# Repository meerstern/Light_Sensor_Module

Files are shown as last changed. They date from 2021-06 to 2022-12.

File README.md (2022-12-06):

# Light_Sensor_Module

Light Sensor Module with APDS-9008-020

## 概要 
  * アナログ光センサ[APDS-9008-020][1]を用いた光センサ基板です  
  * 人の目に近いスペクトル応答性と広い照明範囲にわたる出力線形性のセンサを使用しています  
  * 光強度のアナログ出力(A)と可変抵抗で調整可能な閾値によるデジタル出力(D)を備えています  
  * デジタル出力の状態はLEDで確認できます  
  * コネクタはGrove互換コネクタとなっており、3.3V/5V電源に対応しています  
  * 電源は3V~5.5Vに対応しています  
  * 光センサ感度の可変抵抗、デジタル出力の閾値の可変抵抗を備えています  
  * 本センサは環境負荷の大きなCdSを使用していません  
  * 基板サイズ25mm x30mm、固定穴M3x4 幅19mm x24mm  

## 注意 
  * 可変抵抗は強く回したり、速く動かすと破損する場合があります。ゆっくり動かしてください     
  * 基板裏側の光センサは衝撃や外力に非常に弱いため、取り扱いに注意してください    
 
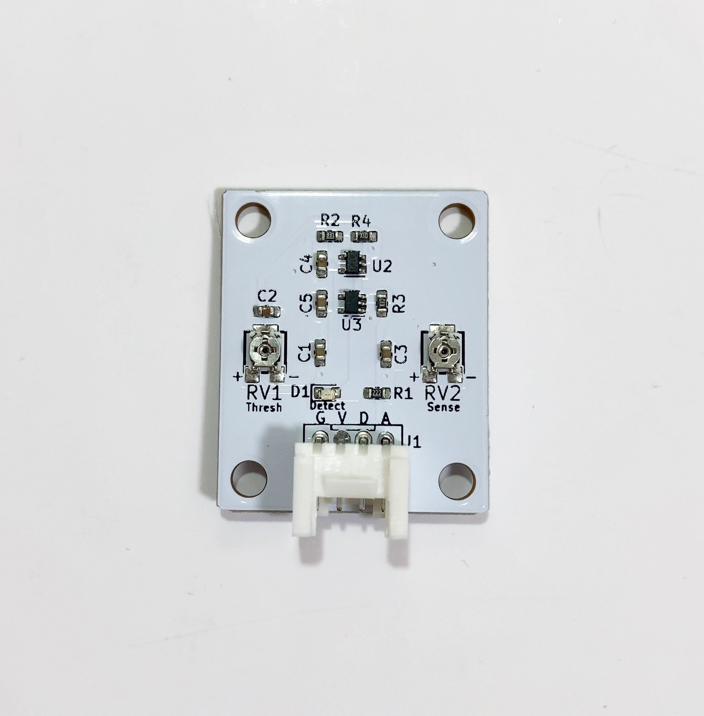
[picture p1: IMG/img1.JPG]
 
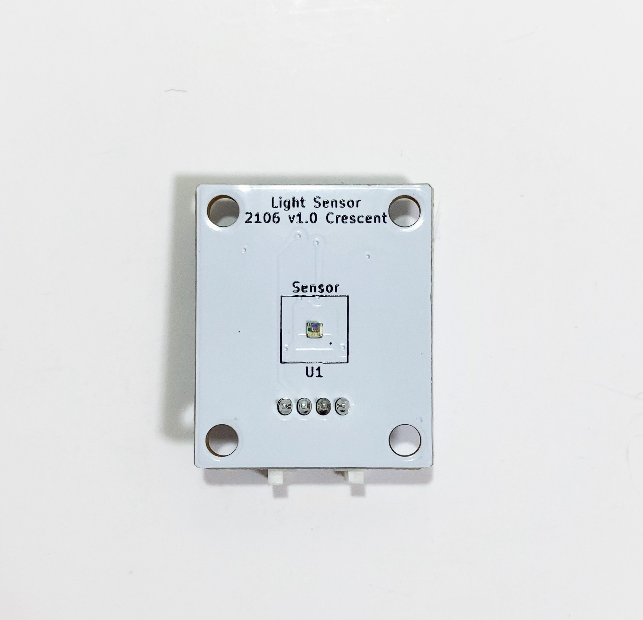
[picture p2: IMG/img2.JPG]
 
 
## 販売サイト
  * [スイッチサイエンス][2]
 
[1]: https://jp.broadcom.com/products/optical-sensors/ambient-light-photo-sensors/apds-9008 "*1"
[2]: https://www.switch-science.com/products/7394
MIT Lisense

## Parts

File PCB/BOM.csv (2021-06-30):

Elecrow PN | Parts | Value | Package | QTY | Digikey/Mouser/Manufacturer Part | Remark/ Link
 | U3 | LM321 | SOT-353_SC-70-5 | 1 | 595-TLV316IDCKR
 | U2 | LMV331 | SOT-353_SC-70-5 | 1 | 595-LMV331IDCKR
 | U1 | APDS-9008 | APDS-9008 | 1 | 630-APDS-9008-020
 | RV2,RV1 | 10k | rcl-RTRIMCVR42A | 2 | 652-TC33X-2-103E
C22859 | R4,R3 | 10 | R_0603_1608Metric | 2
C23138 | R2 | 330 | R_0603_1608Metric | 1
C4190 | R1 | 2.2k | R_0603_1608Metric | 1
 | J1 | Grove | GROVE | 1 | 713-110990037
4040806A | D1 | LED | LED_0603_1608Metric | 1
C14663 | C5,C4,C3,C2,C1 | 0.1u | C_0603_1608Metric | 5

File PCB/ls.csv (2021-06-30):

ID | 参照記号 | パッケージ | 数 | 名称 | Supplier and ref
1 | H4,H3,H2,H1 | MountingHole_3.2mm_M3 | 4 | MountingHole
2 | U3 | SOT-353_SC-70-5 | 1 | LM321
3 | U2 | SOT-353_SC-70-5 | 1 | LMV331
4 | U1 | APDS-9008 | 1 | APDS-9008
5 | RV2,RV1 | rcl-RTRIMCVR42A | 2 | 10k
6 | R4,R3 | R_0603_1608Metric | 2 | 10
7 | R2 | R_0603_1608Metric | 1 | 330
8 | R1 | R_0603_1608Metric | 1 | 2.1k
9 | J1 | GROVE | 1 | Grove
10 | D1 | LED_0603_1608Metric | 1 | LED
11 | C5,C4,C3,C2,C1 | C_0603_1608Metric | 5 | 0.1u

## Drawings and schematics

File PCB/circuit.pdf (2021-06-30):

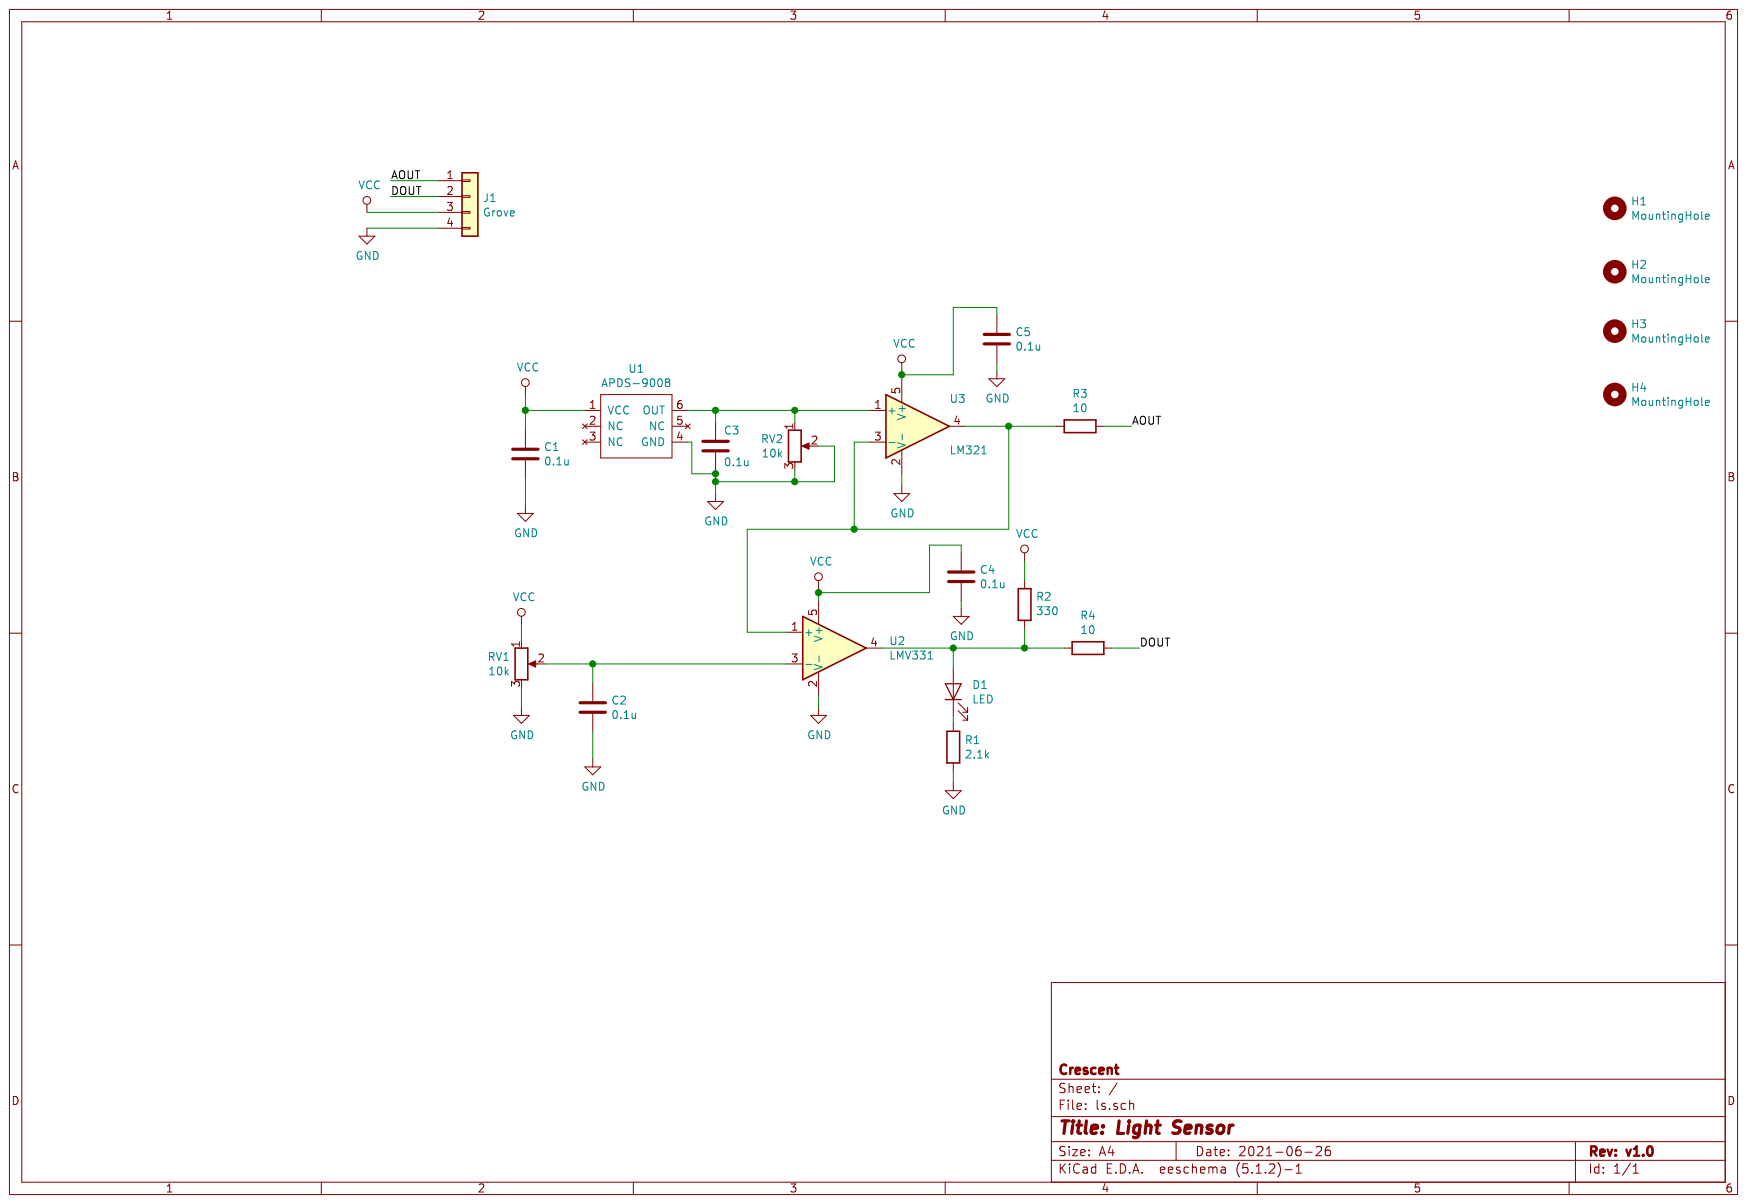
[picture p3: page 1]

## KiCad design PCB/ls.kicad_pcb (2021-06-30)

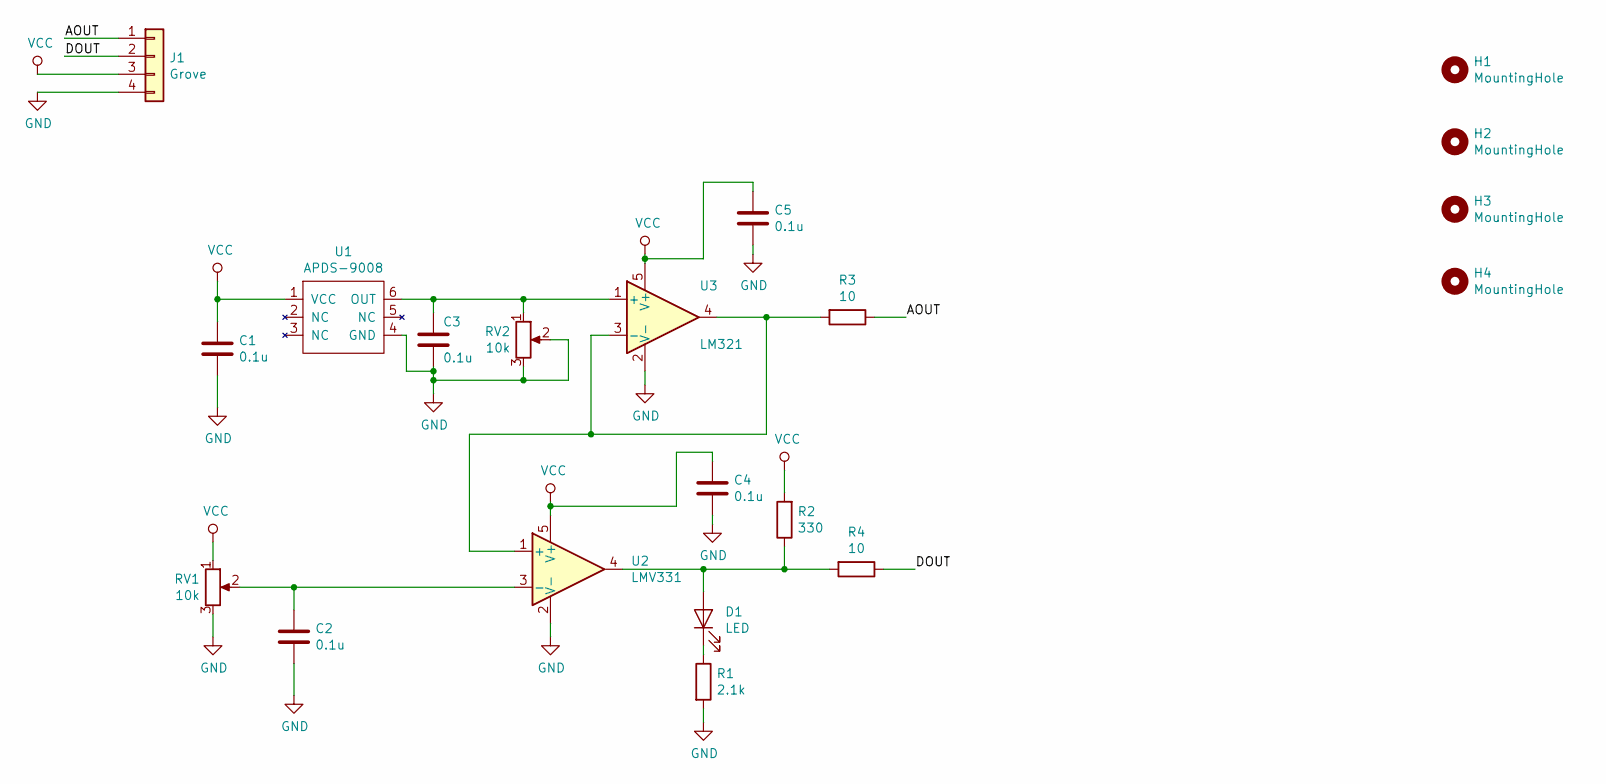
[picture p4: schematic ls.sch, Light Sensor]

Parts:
C1, C2, C3, C4, C5: 0.1u; C_0603_1608Metric
D1: LED; LED_0603_1608Metric
H1, H2, H3, H4: MountingHole; MountingHole_3.2mm_M3
J1: Grove; GROVE
R1: 2.1k; R_0603_1608Metric
R2: 330; R_0603_1608Metric
R3, R4: 10; R_0603_1608Metric
RV1, RV2: 10k; rcl-RTRIMCVR42A
U1: APDS-9008
U2: LMV331; SOT-353_SC-70-5
U3: LM321; SOT-353_SC-70-5

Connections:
/AOUT: J1.1, R3.1
/DOUT: J1.2, R4.1
GND: C1.2, C2.2, C3.2, C4.2, C5.2, J1.4, R1.2, RV1.3, RV2.2, RV2.3, U1.4 (GND), U2.2 (V-), U3.2 (V-)
unnamed: C2.1, RV1.2, U2.3 (-)
unnamed: C3.1, RV2.1, U1.6 (OUT), U3.1 (+)
unnamed: D1.1 (K), R1.1
unnamed: D1.2 (A), R2.1, R4.2, U2.4
unnamed: R3.2, U2.1 (+), U3.3 (-), U3.4
VCC: C1.1, C4.1, C5.1, J1.3, R2.2, RV1.1, U1.1 (VCC), U2.5 (V+), U3.5 (V+)

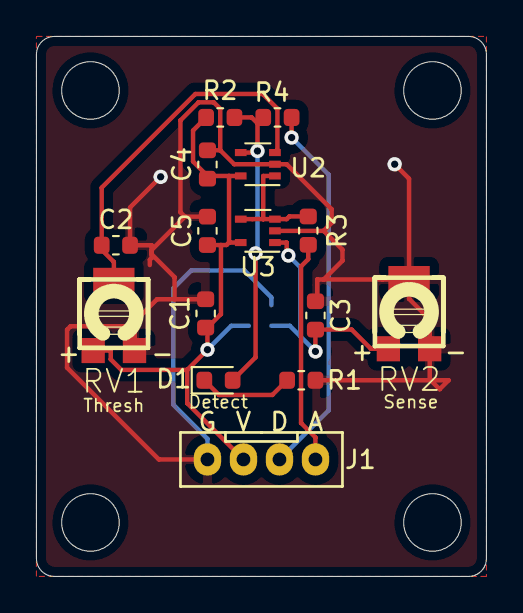
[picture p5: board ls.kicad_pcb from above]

Board: 2 copper layers, 25.0 x 30.0 mm, 20 parts (1 on the bottom side), 9 nets.
